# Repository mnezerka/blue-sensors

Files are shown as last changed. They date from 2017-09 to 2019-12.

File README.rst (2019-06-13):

Blue Sensors
============

Implementation of simple sensors (e.g. temperature) reader and publisher based
on ESP8266 chip.

`Components <doc/components.rst>`_

`Wiring <doc/wiring.rst>`_

`Packaging <doc/packaging.rst>`_

`Build and Deployment <doc/build.rst>`_

`Communication Protocols <doc/protocols.rst>`_

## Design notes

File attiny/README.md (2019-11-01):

# ATTiny

## ATTiny 1634

8 MHz internal clock - burn bootloader

Programmer: USB-ASP - https://docs.platformio.org/en/latest/platforms/atmelavr.html

## Build

Tailor build by setting flags, e.g.::

```
export PLATFORMIO_BUILD_FLAGS=-DINTERVAL_READINGS=120
```

Build and flash to attiny:

```
pio run -t upload

```

Check state of the device by observing serial console:

```
pio device monitor
```

## Troubleshoting

- Not enough permissions to access usb device:
  https://andreasrohner.at/posts/Electronics/How-to-fix-device-permissions-for-the-USBasp-programmer/

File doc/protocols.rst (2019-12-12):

Communication Protocols
=======================

Data are sent over HTTP in POST request. Server replies with HTTP
status codes, where 200 OK means that readings are accepted.

Json format
-----------

Format of the raw http body::

    {
        "device": "DEVICE_ID",
        "ip": "device ip address (optional)",
        "wifi-ssid": "device wifi ssid (optional)",
        "wifi-strength": deivice wifi strength (optional),
        "time: unix_timestamp (optional),
        "readings": [
            {
                "address": "unique sensor address",
                "t": temperature,
                "h": humidity;
                "p": pressure;
            }
        ]
    }

The only mandatory fields on global level are ``device`` (short variant is
``d``) and ``readings`` (short variant is ``r``. Each item in ``readings``
array have to contain ``address`` (short variant is ``a``).

The minimal http chunk could look like::

    {
        "d": "Device123",
        "r": [
            {
                "a": "SensorXYZ",
                "t": 23,
            }
        ]
    }

Encryption
----------

Server accepts both unecrypted and encrypted data. The only supported
algorithm is AES 128bit ECB with PKCS7 padding. Free implementation
in C is available here: https://github.com/mnezerka/blue-aes

Testing
-------

This is simulation of device push executed in command line::

    curl -i -X POST http://your_server -d '{"d":"RED0002","r":[{"a":"28ff9180c1160434","t":22.6},{"a":"RED0002BME","t":22.6,"p":976.6,"h":57.0}]}'

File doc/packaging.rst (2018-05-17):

Packaging
=========

Phase 1 - no boxes
------------------
At the very beginning, a bare chip was inserted into plastic box and fixed to cargo using silver dug tape. There were no peripherals except one Dallas sensor.

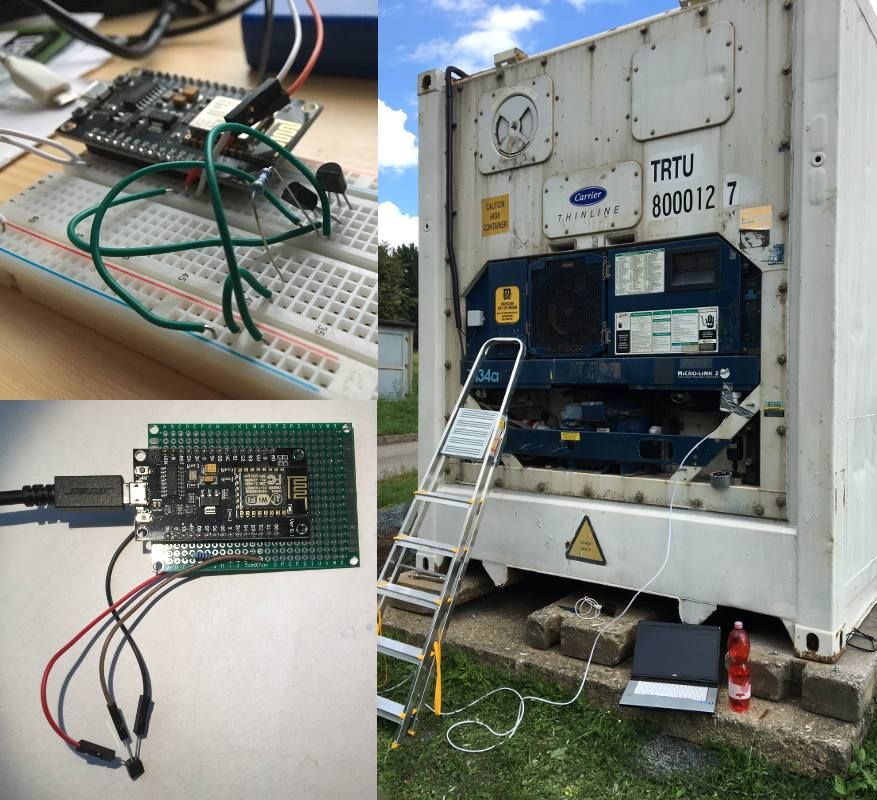
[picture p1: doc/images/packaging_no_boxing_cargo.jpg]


Phase 2 - PLA box
-----------------
Chip is boxed in box printed on 3D printer from PLA plastic. LCD display was added showing various run time information (e.g. wifi connection status, temperatures from all sensors). Cables from sensors are connected to Dupont female connectors soldered on board and available through holes on side of the plastic box. Refer to `boxes` directory for FreeCAD sources of all boxes.

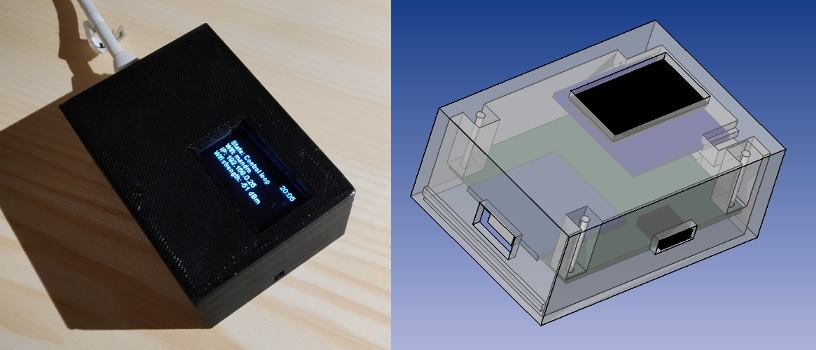
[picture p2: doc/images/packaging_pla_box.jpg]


Phase 3 - TODO
--------------
- prepare box (3D printing) for standard board size (4x6cm)
- if the display is part of the device, it should be attached via dupont cables instead hard soldering
- assemble first prototype with connector for Dallas sensors

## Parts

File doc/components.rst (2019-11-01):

Components
==========

Implementation of simple sensors (e.g. temperature) reader and publisher

Boards
------

All boards are based on ESP8266 chip.

nodemcuv2
.........

https://www.aliexpress.com/item/1pcs-V3-4M-4FLASH-NodeMcu-Lua-WIFI-Networking-development-board-Based-ESP8266/32787382982.html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

Wemos D1 Mini
.............

https://wiki.wemos.cc/products:d1:d1_mini

https://www.aliexpress.com/item/D1-mini-V1-Mini-NodeMcu-4M-bytes-Lua-WIFI-Internet-of-Things-development-board-based-ESP8266/32787418018.html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

PCB
...
Universal PCB board (4x6cm)
https://www.aliexpress.com/item/5PCS-Double-side-Prototype-PCB-Tinned-Universal-board-4x6-4-6cm/32829197097.html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

Peripherials
------------

This is list of supported devices that can be connected and configured via build flags.

Temperature Sensor Dallas (DS18B20)
...................................
One Wire digital temperature sensor from Maxim IC. Reports degrees C with 9 to
12-bit precision, measures temperature from -55C to 125C, accuracty from -10C
to +85C is +/-0.5C. Each sensor has a unique 64-Bit Serial number etched into
it - allows for a huge number of sensors to be used on one data bus.

https://www.aliexpress.com/item/100-New-and-original-DALLAS-DS18B20-TO-92-IC-free-shipping/1327754867.html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

::

               _____
              /     \
             /       \
            +---------+
            |         |
            |         |
            |         |
            +---------+
             |   |   |
         GND |   |   | VCC
             | DATA  |
             |   |   +------------+
             |   |                |
             |   |                |
             |   | +----------+   |
             |   +-+ 4700 ohm +---+
             |   | +----------+   |
             |   |                |
             |   |                |
            GND  DX              3V

4700 ohm resistor (bar colors: yellow, blue, red and white) is needed

Waterproof Temperature Sensor Dallas (DS18B20)
..............................................
Stainless Steel Package 1 Meters Waterproof DS18b20 Temperature Probe Temperature Sensor 18B20
https://www.aliexpress.com/item/Stainless-Steel-Package-1-Meters-Waterproof-DS18b20-Temperature-Probe-Temperature-Sensor-18B20/32359386131.html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

::

                                       +--------------+
        --- red --------+--------------+  waterproof  |
        --- yellow -----|  cable (1m)  |  DS18B20     |
        --- green  -----+--------------+              |
                                       +---------------

BME280 I2C Sensor
.................
https://www.aliexpress.com/item/3In1-BME280-GY-BME280-Digital-Sensor-SPI-I2C-Humidity-Temperature-and-Barometric-Pressure-Sensor-Module-1/32847825408.html

I2C address can be 0x76 or 0x77 (use I2C scanner to detect right value)

Wiring::

    GND <-> GND
    VCC <-> 3V
    SDA <-> D3
    SCL <-> D4

LCD I2C Display
...............

https://www.aliexpress.com/item/IIC-I2C-TWI-Serial-LCD-2004-20x4-Display-Shield-Blue-Backlight-for-Arduino-Free-Shipping/32599904427.html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

OLED ICC Display
................

https://www.aliexpress.com/item/1pcs-Free-Shipping-White-Blue-White-and-Blue-color-0-96-inch-128X64-OLED-Display-Module/32717950155.html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

Wiring::

                           +---------------+
     GND <-> GND           |               |
     VDD <-> 3V3           |     OLED      |
     SCK <-> D5            |    Display    |
     SDA <-> D3            |               |
                           +---------------+
                             |   |   |   |
                            GND VDD SCK SDA
                             .   .   .   .
                             .   ................................
                             .       .   .                      .
                             ................................   .
                                     .   .                  .   .
                                     .   .                  .   .
                     .....................                  .   .
                     .               .                      .   .
                    D3              D5                     GND 3V3
         |   |   |   |   |   |   |   |   |   |   |   |  |   |   |
        +---------------------------------------------------------+
        |                                                         |
        |                                                 FLASH O |
        |                                                         |
        |                                                         |
        |                                                     +---+
        |                                                     |   | USB
        |                                                     |   |
        |                                                     +---+
        |                                                         |
        |                                                  RST  O |
        |                                                         |
        +---------------------------------------------------------+
         |   |   |   |   |   |   |   |   |   |   |   |  |   |   |

Dupont
------

Crimping Tool
.............

https://www.aliexpress.com/item/New-Arrival-SN-28B-Pin-Crimping-Tool-Crimping-Plier-2-54mm-3-96mm-28-18AWG/32649914049.html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

Various connectors
..................

- https://www.aliexpress.com/item/Free-shiiping-Hot-Sale10pcs-40-Pin-1x40-Single-Row-Male-2-54mm-Breakable-Pin-Header-Connector/32699944798.html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
- https://www.aliexpress.com/item/620pcs-A-Set-Dupont-Wire-Jumper-Pin-Header-Connector-Housing-Kit-Male-Crimp-Pins-Female-Pin/32736024614.html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
- https://www.aliexpress.com/item/120Pcs-Lot-10cm-30cm-Color-Ribbon-Line-Breadboard-Dupont-Cable-Jump-Jumper-Wire-Male-to-Male/32798011999.html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
- https://www.aliexpress.com/item/10pcs-2-54mm-1x40-Pin-Right-Angle-Single-Row-Female-Pin-Header-Connector-Strip-Bending/32326267382.html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

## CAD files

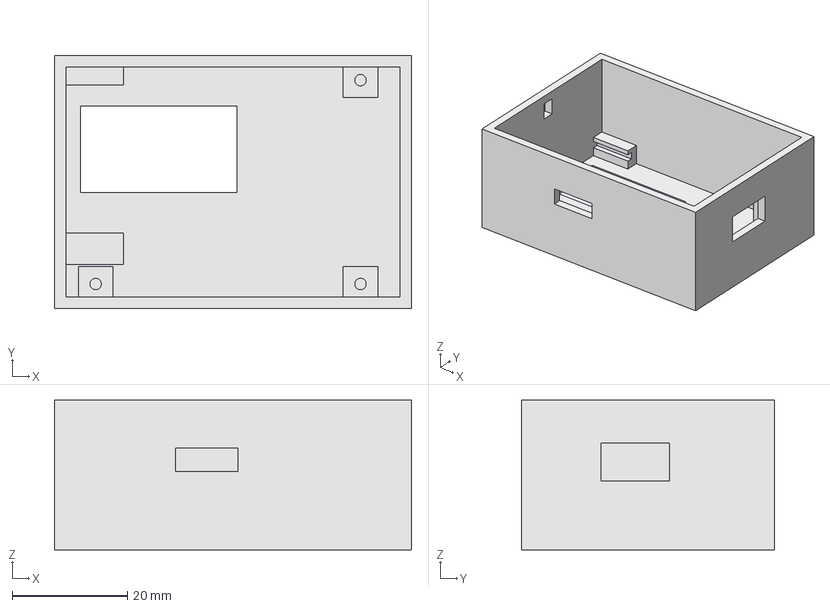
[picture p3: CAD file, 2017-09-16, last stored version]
boxes/box_d1.fcstd
62.0 x 44.0 x 26.0 mm

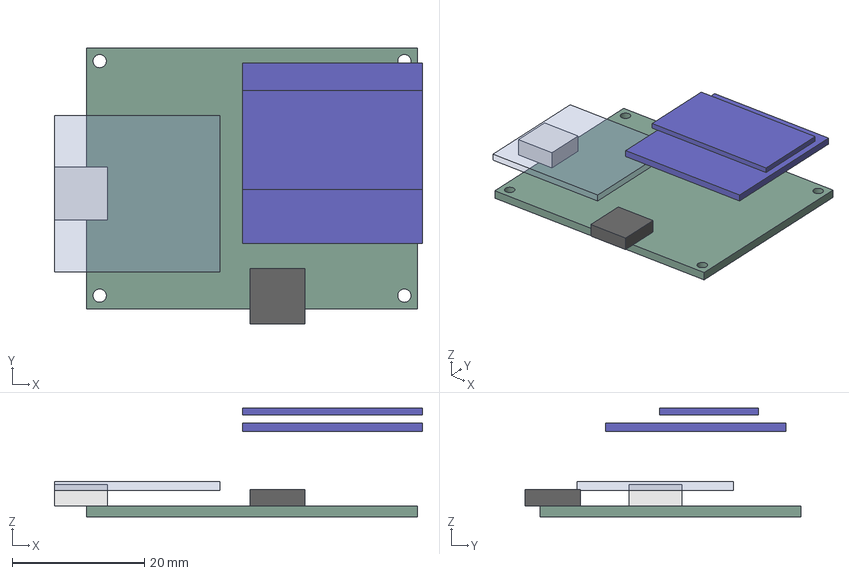
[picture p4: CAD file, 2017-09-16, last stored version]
boxes/d1_on_field_with_oled.fcstd
55.6 x 41.7 x 16.4 mm
Base Field
D1 Field
OLED
Pins Out
USB

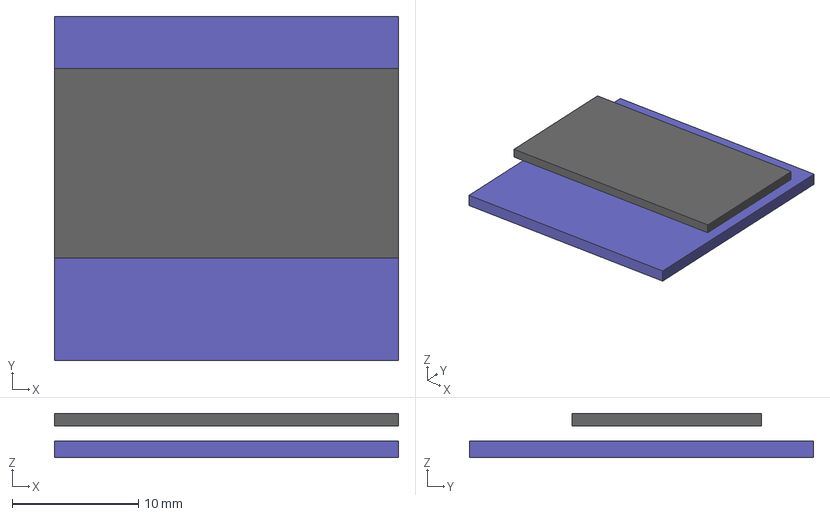
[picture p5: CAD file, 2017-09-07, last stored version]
boxes/oled_display.fcstd
27.2 x 27.2 x 3.50 mm
Field
Display

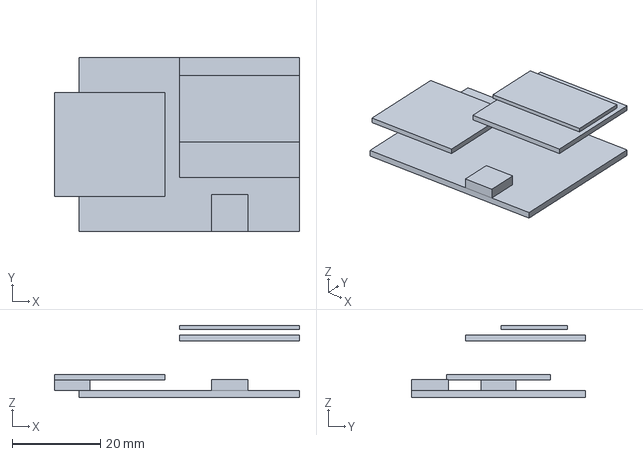
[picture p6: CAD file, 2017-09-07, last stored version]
boxes/d1_display.fcstd
55.6 x 39.4 x 16.4 mm

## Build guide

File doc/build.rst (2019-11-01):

Building
========

Building and deployment (flashing) of software is managed by platform.io
framework.  It is possible to configure buld variant via build flags. One of the possibilities for providing
flags is environment are provided as environment variables::

    export PLATFORMIO_BUILD_FLAGS=-DENABLE_DUMMY_SENSORS
    export PLATFORMIO_BUILD_FLAGS='-DENABLE_DUMMY_SENSORS -DPUSH_URL=\"http://192.168.0.11:9200/api/readings\"'

Available flags:

- `ENABLE_WIFI` - enable wifi connectivity
- `ENABLE_GPRS` - enable gprs connectivity (SIM module must be connected via serial port)
- `ENABLE_LCD` - enable lcd display
- `ENABLE_OLED` - enable oled display
- `ENABLE_DUMMY_SENSOR` - enable dummy temperature sensor which simulates thermo sensor 
- `ENABLE_DALLAS_SENSORS` - enable dallas onewire sensors
- `ENABLE_BME280_SENSORS` - enable BME280 sensor
- `DEVICE_ID` - device identification string
- `INTERVAL_READINGS` - interval (ms) for reading and pushing sensor readings
- `PUSH_URL` - url of the api for processing of pushed readings
- `PUSH_ENCRYPTION_ENABLED` - enable or disable encryption of data pushed over http (default is 0 = no ecryption)
- `PUSH_ENCRYPTION_PASSWORD` - password to be used for http content encryption (shall have 16 characters)
- `PUSH_AES_BUFFER_SIZE` - size of the buffer for complete content sent to the server (default 1024)
- `ONE_WIRE_BUS` - GPIO pin to which is connected one wire data cable (for Dallas sensors)
- `WIRE_SDA` - GPIO pin to which is connected I2C bus SDA
- `WIRE_SCL` - GPIO pin to which is connected I2C bus SCL
- `SENSOR_BMA_ADDR` - address for BMA sensor

Step By Step
------------

List available devices::

    pio device list

Device connected to usb should be in list (in our case `ttyUSB0`)::

    /dev/ttyS0
    ----------
    Hardware ID: PNP0501
    Description: ttyS0

    /dev/ttyUSB0
    ------------
    Hardware ID: USB VID:PID=1A86:7523 LOCATION=1-1.3
    Description: USB2.0-Serial

Tailor build by setting flags, e.g.::

    export PLATFORMIO_BUILD_FLAGS=-DENABLE_DALLAS_SENSORS

Build and flash to selected environment (`d1_mini` in our case)::

    pio run -e d1_mini -t upload

Check state of the device by observing serial console::

    pio device monitor

Troubleshooting
---------------
Try I2C scanner in case of inactive I2C device:
https://github.com/mnezerka/arduino/tree/master/i2c_scanner

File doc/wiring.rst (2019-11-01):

Wiring
======

Example 1 - D1 Mini + Dallas + OLED
-----------------------------------

Dallas sensors are connected to D2, OLED to D3 and D4

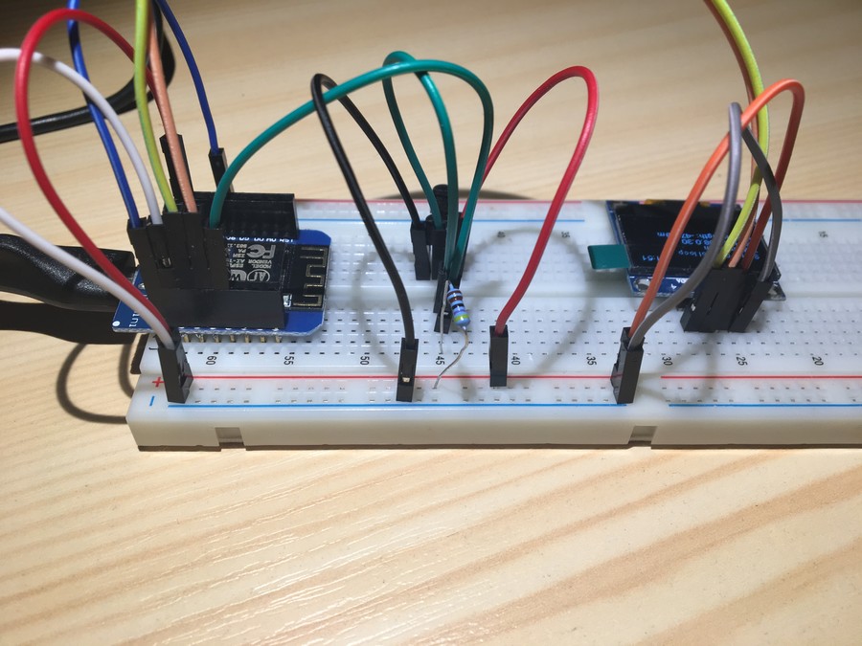
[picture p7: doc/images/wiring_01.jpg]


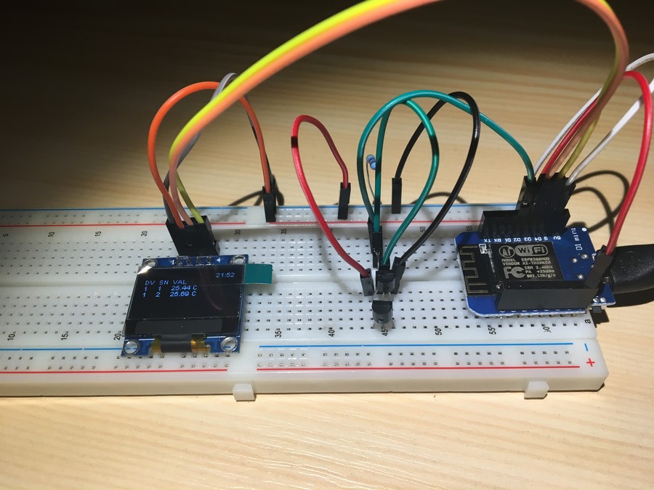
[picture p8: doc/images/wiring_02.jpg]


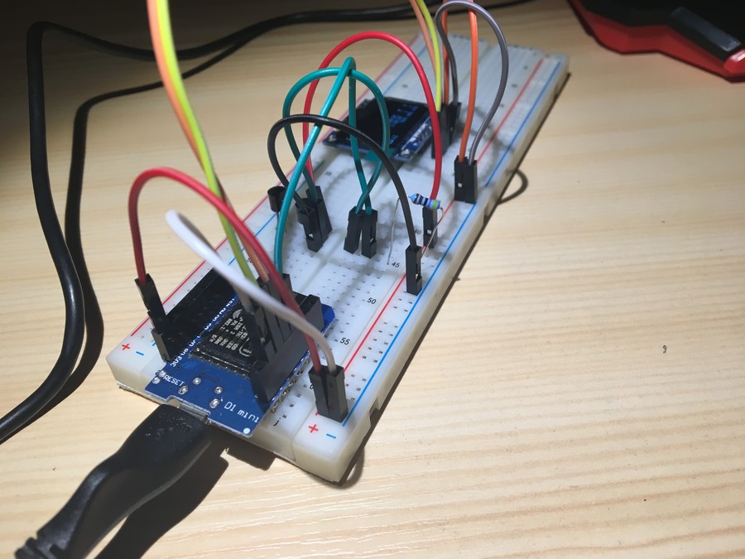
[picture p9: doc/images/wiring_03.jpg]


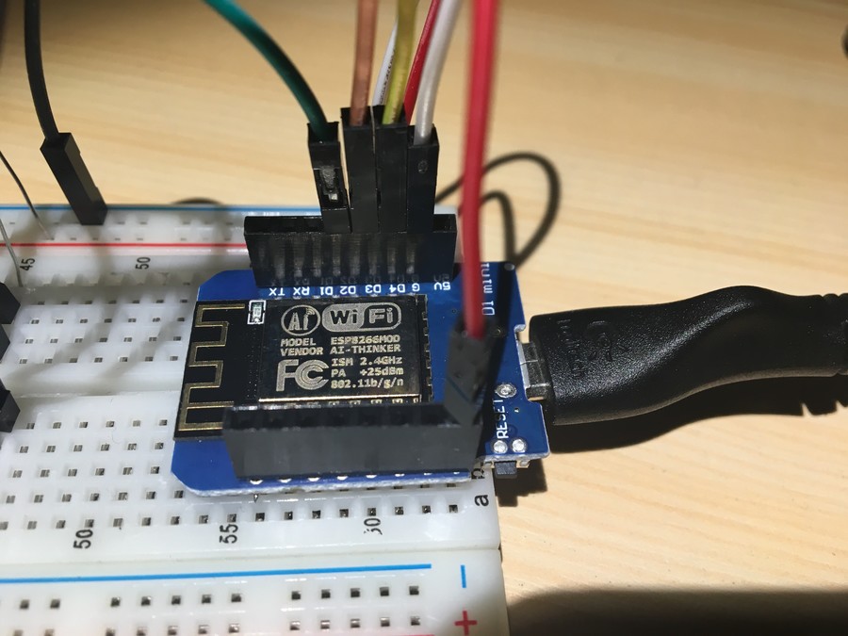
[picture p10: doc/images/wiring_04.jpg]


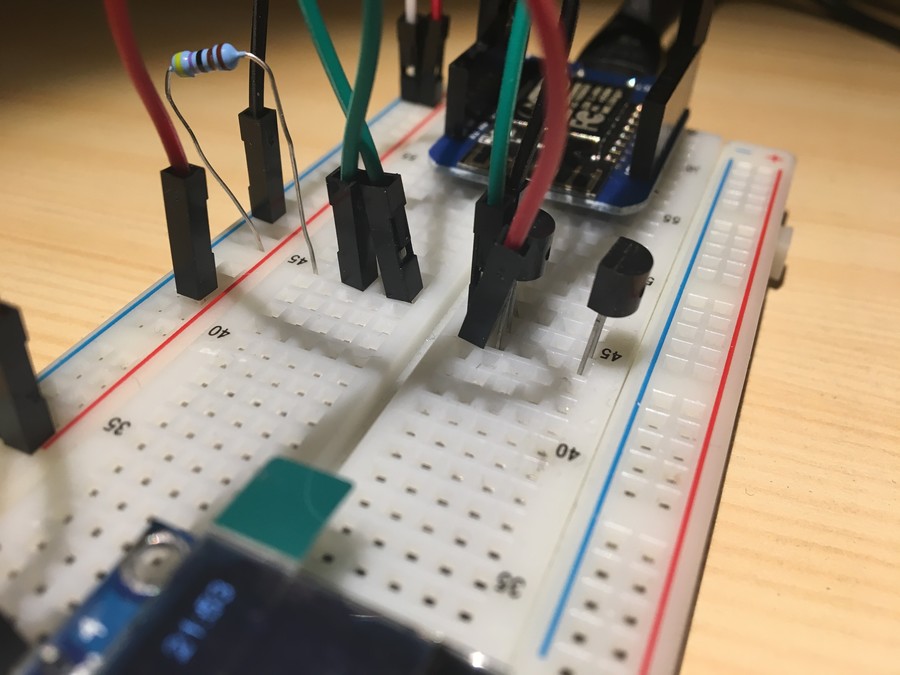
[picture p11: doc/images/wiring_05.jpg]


Screenshots of display after Wifi provisioning - temperature from two sensors
is shown as well as wifi connection information and current time (fetched from
internet via NTP).

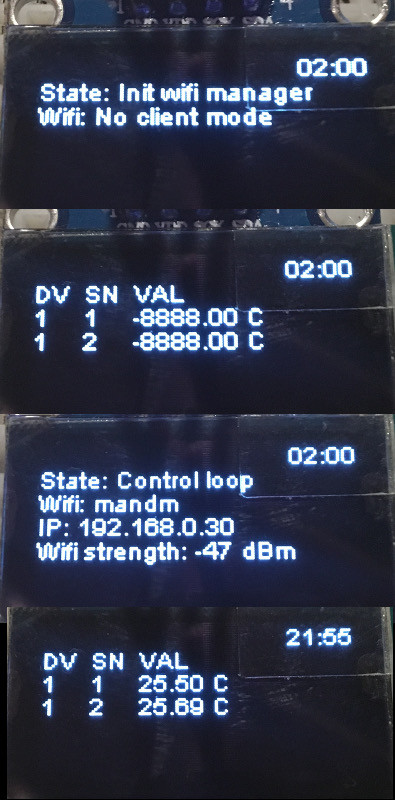
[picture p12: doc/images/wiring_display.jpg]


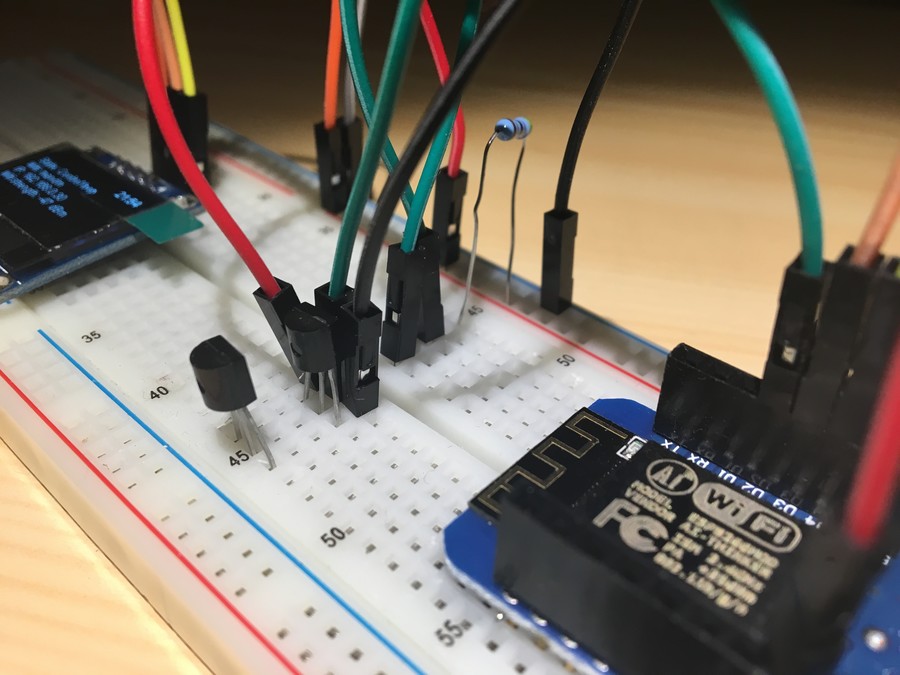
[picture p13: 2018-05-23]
doc/images/wiring_06.jpg

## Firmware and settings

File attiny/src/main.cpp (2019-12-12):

#include "config.h"   // needs to be included first sinc it contains some definitions for other includes (e.g. SoftWire)
#include <OneWire.h>
#include <DallasTemperature.h>
#include "TinyBME280.h"

#define SERBAUD 9600
#define SIMBAUD 38400
#define SIMRESET 2
#define DALLASPIN 5

#define BUFFER_SIZE 64
#define MAX_BODY_SIZE 255

const char server[] PROGMEM = PUSH_HOST;

#define IX_AT 0
const char c0[]     PROGMEM = "AT";
#define IX_AT_IPR 1
const char c1[]     PROGMEM = "AT+IPR=38400"; //The speed must be set also here!
#define IX_AT_CBC 2
const char c2[]     PROGMEM = "AT+CBC";
#define IX_AT_CSTT 3
const char c3[]     PROGMEM = "AT+CSTT=\"internet\",\"\",\"\"";
#define IX_AT_CIICR 4
const char c4[]     PROGMEM = "AT+CIICR";
#define IX_AT_CIPSTATUS 5
const char c5[]     PROGMEM = "AT+CIPSTATUS";
#define IX_AT_CIFSR 6
const char c6[]     PROGMEM = "AT+CIFSR";
#define IX_AT_CIPSEND 7
const char c7[]     PROGMEM = "AT+CIPSEND";
#define IX_AT_CIPSEND1 8
const char c8[]     PROGMEM = "AT+CIPQSEND=1";
#define IX_AT_CIPCLOSE 9
const char c9[]     PROGMEM = "AT+CIPCLOSE";
#define IX_AT_CIPSHUT 10
const char c10[]    PROGMEM = "AT+CIPSHUT";
#define IX_AT_CSCLK2 11
const char c11[]    PROGMEM = "AT+CSCLK=2";
#define IX_AT_CIPSTART 12
const char c12[]    PROGMEM = "AT+CIPSTART=\"TCP\",\"";
#define IX_HTTP_METHOD 16
const char c16[]    PROGMEM = "POST ";
#define IX_EOL 17
const char c17[]    PROGMEM = "\r\n";
#define IX_HTTP_HEADER_HOST 18
const char c18[]    PROGMEM = "Host: ";
#define IX_HTTP_HEADER_USER_AGENT 19
const char c19[]    PROGMEM = "User-Agent: ArduinoSIM800";
#define IX_HTTP_HEADER_CONNECTION_CLOSE 20
const char c20[]    PROGMEM = "Connection: close";
#define IX_HTTP_HEADER_CONTENT_TYPE 21
const char c21[]    PROGMEM = "Content-Type: application/json";
#define IX_HTTP_HEADER_CONTENT_LENGTH 22
const char c22[]    PROGMEM = "Content-Length: ";
#define IX_HTTP_PROTOCOL 23
const char c23[]    PROGMEM = " HTTP/1.1";
#define IX_HTTP_BODY_DEVICE 24
const char c24[]    PROGMEM = "{\"d\":\"";
#define IX_HTTP_BODY_READINGS 25
const char c25[]    PROGMEM = "\",\"r\":[";
#define IX_HTTP_BODY_READING_ADDR 26
const char c26[]    PROGMEM = "{\"a\":\"";
#define IX_HTTP_BODY_READING_TEMP 27
const char c27[]    PROGMEM = "\",\"t\":";
#define IX_HTTP_BODY_READING_PRESS 28
const char c28[]    PROGMEM = ",\"p\":";
#define IX_HTTP_BODY_READING_HUM 29
const char c29[]    PROGMEM = ",\"h\":";
#define IX_HTTP_BODY_READING_ADDR_END 30
const char c30[]    PROGMEM = "";
#define IX_HTTP_BODY_READING_END 31
const char c31[]    PROGMEM = "}";
#define IX_HTTP_BODY_END 32
const char c32[]    PROGMEM = "]}";
const char c33[]    PROGMEM = "Modem reset";
#define IX_AT_CIPSENDQ 34
const char c34[]    PROGMEM = "AT+CIPSEND?";
#define IX_BME 35
const char c35[]    PROGMEM = "BME";


const char *const string_table[] PROGMEM = {c0, c1, c2, c3, c4, c5, c6,
c7, c8, c9, c10, c11, c12, "", server, "", c16, c17, c18, c19, c20,
c21, c22, c23, c24, c25, c26, c27, c28, c29, c30, c31, c32, c33, c34,
c35};

char buffer[BUFFER_SIZE];
char body[MAX_BODY_SIZE];
char tmp[10];
bool fail = false;
bool modify = false;
bool success = false;
char endcom[2];
unsigned long timer;
const unsigned long wait = INTERVAL_READINGS;

const int VALUE_NA = -8888;

// initialize libraries
OneWire ow(DALLASPIN);
DallasTemperature dallas(&ow);
SoftWire swire = SoftWire();
TinyBME280 bme = TinyBME280(&swire);

void prepare(byte which) {
    strcpy_P(buffer, (char *)pgm_read_word(&(string_table[which])));
}

void prepareAndSend(byte which) {
    prepare(which);
    Serial.print(buffer);
}

void resetModem()
{
    fail = false;
    Serial1.println("Modem reset");
    pinMode(SIMRESET, OUTPUT);
    digitalWrite(SIMRESET, LOW);
    delay(50);
    pinMode(SIMRESET, INPUT_PULLUP);
}

void sendCommand()
{
    Serial1.print(">>> ");
    Serial1.print(buffer);
    Serial.print(buffer);

    // modify flag just adds host name and port after current command
    if (modify) {
        Serial.print(PUSH_HOST); Serial.print("\","); Serial.print(PUSH_PORT);
    }

    Serial1.println();
    Serial.println();
}

void receiveCommand()
{
    unsigned long stamp;
    success = false;
    char thischar = 0;
    stamp = millis();
    byte i = 1;

    while (!Serial.available() && millis() < stamp + 5000) {
        delay(50);
    }
    if (millis() > stamp + 5000) fail = true;
    delay(100);

    while (Serial.available()) {
        thischar = Serial.read();
        Serial1.write(thischar);

        buffer[i] = thischar;

        // check if last chars form word "OK"
        if (buffer[i - 1] == 'O' && buffer[i] == 'K') success = true;

        i++;
        if (i >= BUFFER_SIZE - 4) i = 1;
    }
    Serial1.println();
}

void communicate(byte ix)
{
    prepare(ix);

    if (!fail) {
        sendCommand();
        receiveCommand();
    }
}

// send http body
void prepareBody()
{
    body[0] = '\0';

    prepare(IX_HTTP_BODY_DEVICE); strcat(body, buffer);
    strcat(body, DEVICE_ID);
    prepare(IX_HTTP_BODY_READINGS); strcat(body, buffer);

    int sensors = 0;

    // DALLAS SENSORS

    Serial1.print("Number of dallas devices: ");
    Serial1.println(dallas.getDeviceCount());

    dallas.requestTemperatures();

    // get all sensor readings and generate appropriate reading attributes
    for(sensors = 0; sensors < dallas.getDeviceCount(); sensors++)
    {
        // readings delimter
        if (sensors > 0) strcat(body, ",");

        DeviceAddress deviceAddress;

        // get unique address of sensor
        dallas.getAddress(deviceAddress, sensors);

        prepare(IX_HTTP_BODY_READING_ADDR); strcat(body, buffer);
        // get string representation of a dallas device address
        for (uint8_t i = 0; i < 8; i++)
        {
            // zero pad the address if necessary
            if (deviceAddress[i] < 16) strcat(body, "0");
            sprintf(tmp, "%x", deviceAddress[i]);
            strcat(body, tmp);
        }
        prepare(IX_HTTP_BODY_READING_TEMP); strcat(body, buffer);

        // get temperature
        float temp = dallas.getTempCByIndex(sensors);
        if (temp == -127) temp = VALUE_NA;
        //sprintf(tmp, "%f", temp);
        dtostrf(temp, 4, 1, tmp);
        strcat(body, tmp);
        prepare(IX_HTTP_BODY_READING_END); strcat(body, buffer);
    }

    // BME280

    if (bme.isAvailable()) {

        // readings delimter
        if (sensors > 0) strcat(body, ",");

        prepare(IX_HTTP_BODY_READING_ADDR); strcat(body, buffer);

        strcat(body, DEVICE_ID);
        prepare(IX_BME); strcat(body, buffer);


        // get temperature
        prepare(IX_HTTP_BODY_READING_TEMP); strcat(body, buffer);
        int32_t val = bme.temperature();
        float valf = val / 100.0f;
        dtostrf(valf, 4, 1, tmp);
        strcat(body, tmp);

        // get pressure
        prepare(IX_HTTP_BODY_READING_PRESS); strcat(body, buffer);
        val = bme.pressure();
        valf = val / 100.0f;
        dtostrf(valf, 4, 1, tmp);
        strcat(body, tmp);

        // get humidity
        prepare(IX_HTTP_BODY_READING_HUM); strcat(body, buffer);
        val = bme.humidity();
        valf = val / 100.0f;
        dtostrf(valf, 4, 1, tmp);
        strcat(body, tmp);
        prepare(IX_HTTP_BODY_READING_END); strcat(body, buffer);

    } else {
        Serial1.println("BME280 not available");
    }

    prepare(IX_HTTP_BODY_END); strcat(body, buffer);

    Serial1.println(body);
}

// send HTTP payload
void sendPayload()
{
    // prepare body in buffer to be able to compute
    // its length when writing HTTP Content-length header
    prepareBody();
    //Serial1.print(body);
    Serial1.print("Body length: ");
    Serial1.println(strlen(body));

    // request line
    prepareAndSend(IX_HTTP_METHOD);
    Serial.print(PUSH_PATH);
    prepareAndSend(IX_HTTP_PROTOCOL);
    prepareAndSend(IX_EOL);

    // headers
    prepareAndSend(IX_HTTP_HEADER_HOST); Serial.print(PUSH_HOST); prepareAndSend(IX_EOL);
    prepareAndSend(IX_HTTP_HEADER_USER_AGENT); prepareAndSend(IX_EOL);
    prepareAndSend(IX_HTTP_HEADER_CONNECTION_CLOSE); prepareAndSend(IX_EOL);
    prepareAndSend(IX_HTTP_HEADER_CONTENT_TYPE); prepareAndSend(IX_EOL);
    prepareAndSend(IX_HTTP_HEADER_CONTENT_LENGTH);
    Serial.print(strlen(body) + 4); // 4 newlines (not sure, may be 2 additional bytes would be more precise)
    prepareAndSend(IX_EOL);

    // new line to separate headers and body
    prepareAndSend(IX_EOL);

    /// body
    Serial.print(body);

    // two empty lines at the end of the body
    prepareAndSend(IX_EOL);
    prepareAndSend(IX_EOL);

    Serial.print(endcom);
    Serial.print(endcom);
}

void gprs() {
    timer = millis();

    /*
    prepareBody();
    Serial1.println(body);

    return;
    */

    Serial.println("AT");
    delay(500);

    communicate(IX_AT);
    communicate(IX_AT_IPR); //The speed must be set also here!
    communicate(IX_AT_CBC);
    communicate(IX_AT_CSTT);
    if (!success)
    {
        Serial1.println("Not registered in network");
        resetModem();
        return;
    }

    communicate(IX_AT_CIICR); // starts wireless connection with the GPRS, it obtains IP addres from provider
    communicate(IX_AT_CIPSTATUS);
    communicate(IX_AT_CIFSR); // gets the ip address
    modify = true;
    communicate(IX_AT_CIPSTART); // starts TCP connection
    modify = false;
    if (!fail) delay (3000);
    communicate(IX_AT);
    communicate(IX_AT);
    communicate(IX_AT);
    communicate(IX_AT_CIPSEND1); // select data transmitting mode

    //send data
    communicate(IX_AT_CIPSEND);
    if (!fail) {
        delay(2000);
        sendPayload();
        delay(2000);
    }

    communicate(IX_AT_CIPSENDQ);
    communicate(IX_AT_CIPCLOSE);
    communicate(IX_AT_CIPSHUT);
    communicate(IX_AT_CSCLK2);

    if (!success) fail = true;

    if (fail)
    {
        resetModem();
    }
}

void setup() {
   endcom[0] = 0x1a;
   endcom[1] = '\0';

   Serial1.begin(SERBAUD);
   Serial.begin(SIMBAUD);

   dallas.begin();
   swire.begin();
   bme.begin();

   gprs();
}

void loop() {
   delay(100);
   if (millis() - timer > wait * 1000) {
       gprs();
   }
}

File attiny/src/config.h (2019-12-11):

#ifndef CONFIG_H
#define CONFIG_H

// device identification (for various purposes)
#ifndef DEVICE_ID
#define DEVICE_ID "device001"
#endif

// define interval for reading data from sensors (in seconds)
#ifndef INTERVAL_READINGS
#define INTERVAL_READINGS 60
#endif

#ifndef PUSH_HOST
#define PUSH_HOST "some.domain.org"
#endif

#ifndef PUSH_PORT
#define PUSH_PORT 80
#endif

#ifndef PUSH_PATH
#define PUSH_PATH "/path/to/handler"
#endif

#define SDA_PORT PORTA
#define SCL_PORT PORTA
#define SDA_PIN 4
#define SCL_PIN 1


#endif

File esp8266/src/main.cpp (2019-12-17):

//#include <SPI.h> // this needs to be included to fix problem with complilation
//#include <Wire.h>
#include <Timer.h> // http://playground.arduino.cc/Code/Timer#Installation (https://github.com/JChristensen/Timer)
#include <OneWire.h>
#include "config.h"

#ifdef ENABLE_WIFI
#include "WifiConnectivity.h"
#include "WifiHttpUploader.h"
#else
#include <ESP8266WiFi.h>
#endif

#ifdef ENABLE_GPRS
#include "GprsConnectivity.h"
#endif

#ifdef ENABLE_LOCAL_HTTP_SERVER
#include "ThermoHttpServer.h"
#endif

#include "DeviceState.h"
#include "SerialWriter.h"

#include "Sensors.h"
#include "SensorDallas.h"
#include "SensorBME280.h"
#include "SensorDummy.h"

#ifdef ENABLE_TIME
#include "TimeProvider.h"
#endif

// Setup a oneWire instance to communicate with any OneWire devices (not just Maxim/Dallas temperature ICs)
OneWire oneWire(ONE_WIRE_BUS);

// Instance of global timer
Timer t;

// Instance of writer to serial interface
SerialWriter serialWriter;


#ifdef ENABLE_WIFI
// Instance of readings uploader (http client)
WifiHttpUploader wifiHttpUploader;
#endif

// Instance of Dallas sensor interface
#ifdef ENABLE_DALLAS_SENSORS
SensorDallas dallas(&oneWire);
#endif

// Instance of BME280 sensor interface
#ifdef ENABLE_BME280_SENSORS
SensorBME280 bme;
#endif

#ifdef ENABLE_DUMMY_SENSOR
SensorDummy dummy;
#endif

#ifdef ENABLE_WIFI
// Instance of wifi connectivity wrapper
WifiConnectivity wifiConnectivity;
#endif

#ifdef ENABLE_GPRS
// Instance of gprs connectivity wrapper
GprsConnectivity gprs;
#endif

// Instance of the simple web server
#ifdef ENABLE_LOCAL_HTTP_SERVER
ThermoHttpServer httpServer;
#endif

void takeReadings();
void handleHttpClient();
void handleDeviceState();

void setup(void)
{
    //Wire.begin(WIRE_SDA, WIRE_SCL);
    //Wire.begin(D3, D4);
    //Wire.setClock(100000);

    // init device state listeners
    DeviceState::getInstance().addListener(&serialWriter);

    DeviceState::getInstance().begin();

#ifdef ENABLE_TIME
    // init time provider
    TimeProvider::getInstance().begin();
#endif

    // init all sensors
#ifdef ENABLE_DALLAS_SENSORS
    Sensors::getInstance().addSensor(&dallas);
#endif

#ifdef ENABLE_BME280_SENSORS
    Sensors::getInstance().addSensor(&bme);
#endif

#ifdef ENABLE_DUMMY_SENSOR 
    Sensors::getInstance().addSensor(&dummy);
#endif

    Sensors::getInstance().begin();

#ifdef ENABLE_WIFI
    // init wifi manager
    wifiConnectivity.begin();
#else
    WiFi.mode(WIFI_OFF);
#endif

#ifdef ENABLE_GPRS
    // init gdpr
    gprs.begin();
#endif

#ifdef ENABLE_LOCAL_HTTP_SERVER
    // init http server
    httpServer.begin();
#endif

    // configure control loop
    DeviceState::getInstance().state("Control loop");
    t.every(INTERVAL_READINGS * 1000, takeReadings);

#ifdef ENABLE_LOCAL_HTTP_SERVER
    t.every(100, handleHttpClient);
#endif

    t.every(800, handleDeviceState);
}

//////////////////////////// LOOP /////////////////////////////

int loopFirst = true;

void loop(void)
{
    if (loopFirst) {
        loopFirst = false;
        takeReadings();
    }

#ifdef ENABLE_TIME
    TimeProvider::getInstance().update();
#endif

    t.update();
}

#ifdef ENABLE_LOCAL_HTTP_SERVER
void handleHttpClient()
{
    httpServer.handleClient();
}
#endif

void handleDeviceState()
{
    DeviceState::getInstance().update();
}

void takeReadings()
{
    // take readings of all registered sensors
    Sensors::getInstance().takeReadings();

    serialWriter.processReadings();

#ifdef ENABLE_WIFI
    wifiHttpUploader.processReadings();
#endif

    //String push_data = CommProtocol::readings2Json();
    //DeviceState::getInstance().debug(push_data);

    //gprs.processReadings(push_data);
}

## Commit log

2017-08-30 Sensors instance switched to singleton
2017-09-06 First draft of the box
    [d1_display.fcstd]
2017-09-07 Work on box
    [d1_display.fcstd]
2017-09-07 Shapes for boxes
    [d1_display.fcstd, d1_on_field_with_oled.fcstd, oled_display.fcstd]
2017-09-08 Work on first box
    [box_d1.fcstd, d1_on_field_with_oled.fcstd]
2017-09-16 D1 box without cover
    [box_d1.fcstd, d1_on_field_with_oled.fcstd]
2017-09-16 D1 box first prototype with cover holes
    [box_d1.fcstd]
2017-09-21 Support for BMA280 sensor together with refactoring of readings list
2018-05-30 Fixed propagation of device id
    [config.h]
2019-10-30 ATTiny prototype
2019-11-01 Repository restructuring due to new chip family (attiny)
    [box_d1.fcstd, d1_on_field_with_oled.fcstd, oled_display.fcstd]
2019-11-11 Enhance ESP measurements of pressure
2019-12-10 Prototype of attiny + bme280
2019-12-17 Big refactoring of ESP8266 variant
    - where possible, libraries are referenced on github instead
    of local file system (stored as part of this github repo)
    - small changes to be compliant with latest lib versions
    (e.g. wifi)
    - removed stuff related to LED and OLED displays (rollback
    possible - tag was created before all changes)
    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
2020-06-05 fix bug in dummy sensor
